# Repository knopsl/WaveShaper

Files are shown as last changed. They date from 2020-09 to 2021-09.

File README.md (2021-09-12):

# VC 4046 Wave Shaper

**Prototype has been tested, some issues found. Corrected version not yet tested! ASSUME NOTHING WORKS UNTIL THIS NOTICE IS REMOVED!**

This is a modification of the Barton Musical Circuits [4046 Wave Shaper](http://www.bartonmusicalcircuits.com/4046/), a module described by Barton as follows:

> This is an all analog synthesizer module used to create new timbres and waveforms with your existing VCOs. It uses a CD4046 phase locked loop chip in combination with a binary counter to multiply the frequency of the input signal. It then has 7 outputs divided down from that multiplied frequency which are mixed together. It's simple to use and has a distinct sound.

In Barton's design the seven signals (which are 0, 1, 2, and 3 octaves above and below the input signal) go into a simple mixer with a potentiometer attenuator on each channel to produce the module output. This modification replaces that simple mixer with a voltage controlled mixer, allowing use of control voltages to modulate the mix. If any of the seven control voltage jacks does not have anything plugged in, the CV is normalled to +10 V allowing the pot to behave like a signal attenuator.

An additional modification to Barton's design is that the gain on the output stage can be varied using a pot on the panel. This allows reducing the gain to avoid clipping when mixing multiple large signals, avoiding the need to turn down all the channel pots and allowing use of their full range.

The module consists of a front panel and three PCBs. One of these is the PCB for the original 4046 Wave Shaper, available from Barton, assembled mostly as designed but with a few things changed. The second is a PCB holding the board mounted pots and switch as well as the parts associated with the voltage controlled mixer and the power input section. The third just holds the board mounted input and output jacks.

## Photos

to be added

## Documentation

* [Schematic](Docs/waveshaper.pdf)
* PCB layout: [front](Docs/waveshaper_layout_front.pdf), [back](Docs/waveshaper_layout_back.pdf)
* [BOM](Docs/waveshaper_bom.md)
* [Build notes](Docs/build.md)

## GitHub repository

* [https://github.com/holmesrichards/WaveShaper](https://github.com/holmesrichards/WaveShaper)

## Submodules

This repo uses submodules aoKicad and Kosmo_panel, needed by KiCad. To clone:

```
git clone git@github.com:holmesrichards/WaveShaper.git
git submodule init
git submodule update
```

Alternatively do

```
git clone --recurse-submodules git@github.com:holmesrichards/WaveShaper.git
```

Or if you download the repository as a zip file, you must also click on the "aoKicad" and "Kosmo\_panel" links on the GitHub page (they'll have "@ something" after them) and download them as separate zip files which you can unzip into this repo's aoKicad and Kosmo\_panel directories.

If desired, copy the files from aoKicad and Kosmo\_panel to wherever you prefer (your KiCad user library directory, for instance, if you have one). Then in KiCad, add symbol libraries 

```
aoKicad/ao_symbols
Kosmo_panel/Kosmo
```
and footprint libraries 
```
aoKicad/ao_tht
Kosmo_panel/Kosmo_panel.
```

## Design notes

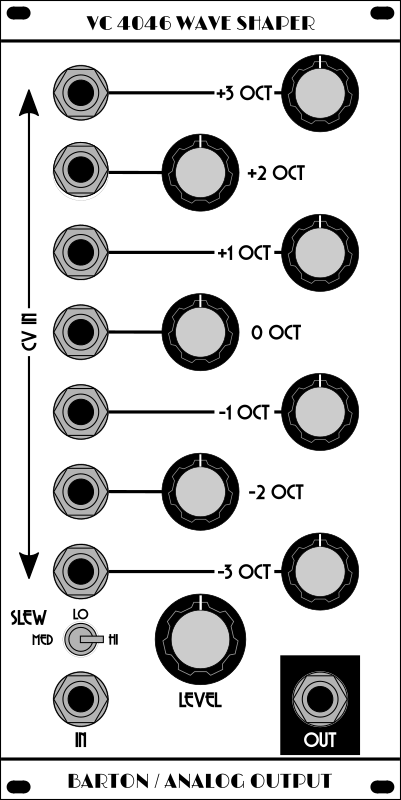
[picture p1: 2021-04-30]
Hardware/Panel/waveshaper.png

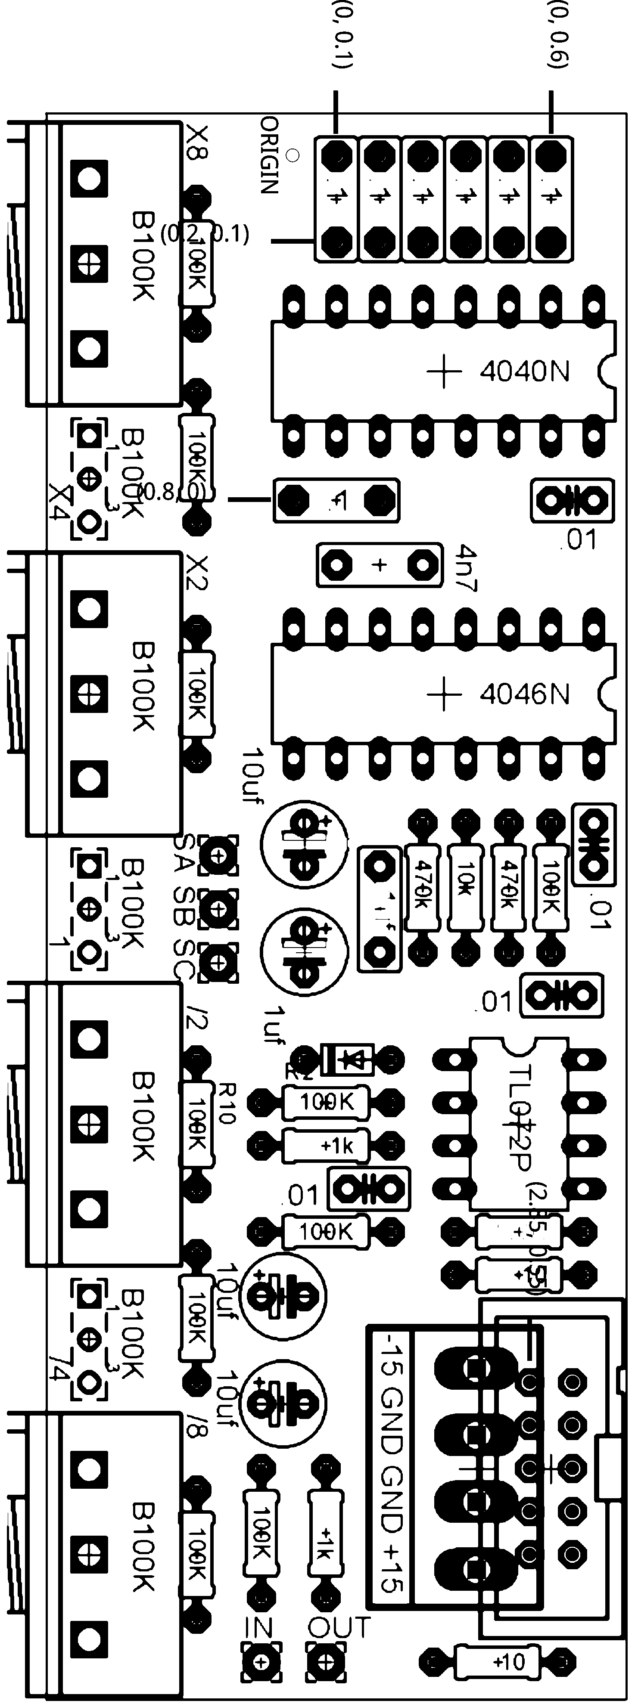
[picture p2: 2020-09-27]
Hardware/PCB-aux/waveshaper-aux/waveshaper_bartonboardbw.png

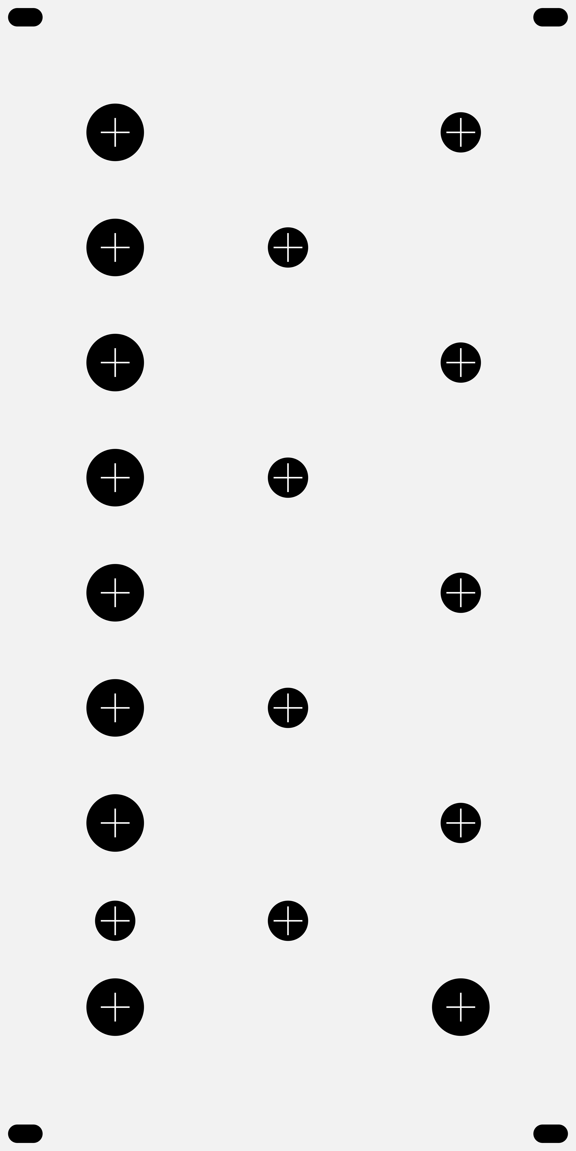
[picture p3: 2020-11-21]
Hardware/Panel/waveshaper_holes.png

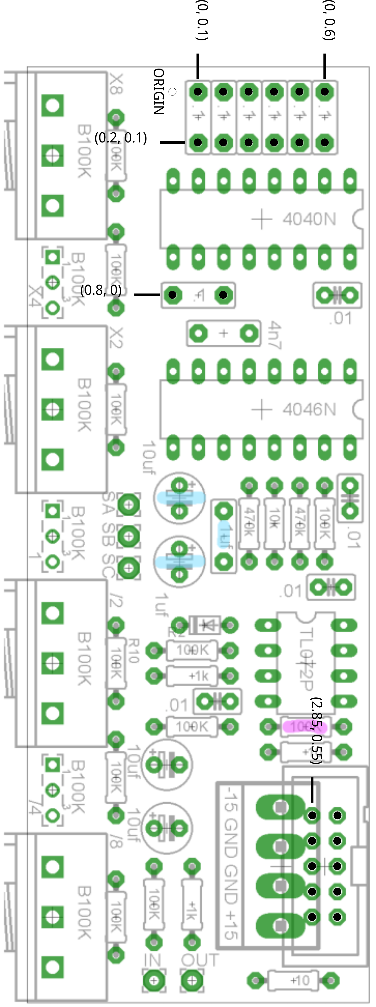
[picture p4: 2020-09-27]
Hardware/PCB-aux/waveshaper-aux/waveshaper_bartonboard.png

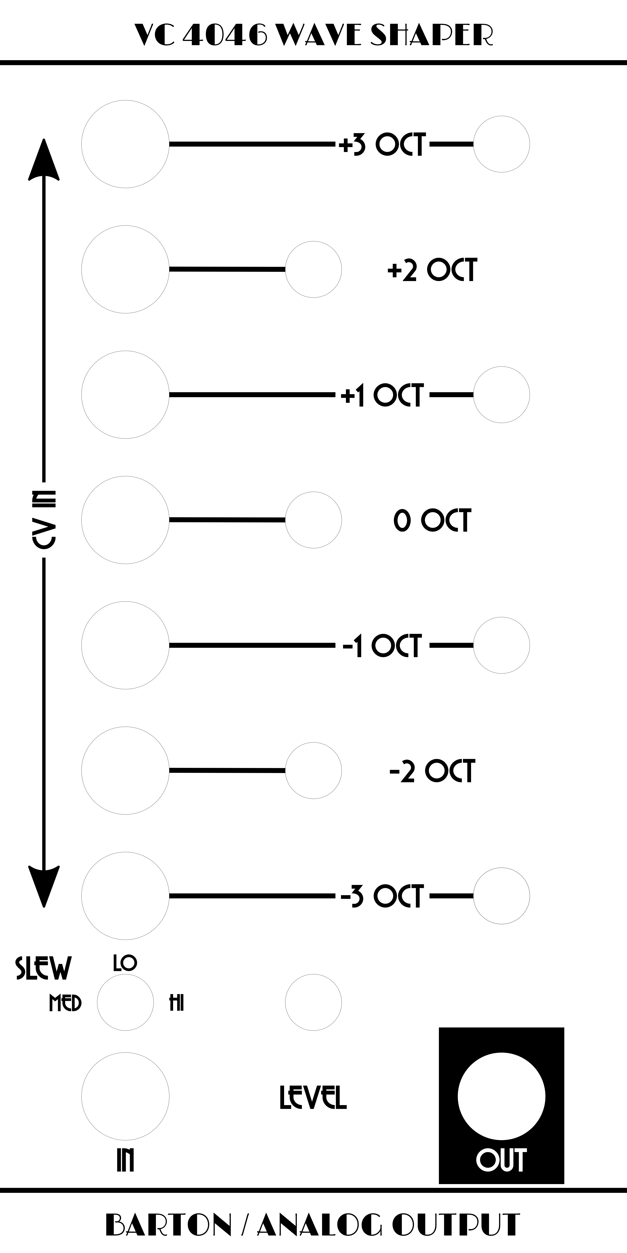
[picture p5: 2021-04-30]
Hardware/Panel/waveshaper_art.png

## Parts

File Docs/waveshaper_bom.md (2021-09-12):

# waveshaper.sch BOM

Sat 11 Sep 2021 09:26:15 PM EDT

Generated from schematic by Eeschema 5.1.10-88a1d61d58~90~ubuntu20.04.1

**Component Count:** 57

| Refs | Qty | Component | Description | Vendor | SKU |
| ----- | --- | ---- | --- | ---- | ---- |
| C1, C2 | 2 | 10uF | Polarized capacitor | Tayda | A-4349 |
| C3, C4 | 2 | 0.1uF | Unpolarized capacitor | Tayda | A-553 |
| D1, D2, D3, D4, D5, D6, D7, D8, D9 | 9 | 1N5817 | Schottky Barrier Rectifier Diode, DO-41 | Tayda | A-159 |
| J1 | 1 | 2x7 IDC header | Generic connector, double row, 02x07, odd/even pin numbering scheme (row 1 odd numbers, row 2 even numbers), script generated (kicad-library-utils/schlib/autogen/connector/) | Tayda | A-3349 |
| J2, J3, J6, J10, J12, J14, J15, J16, J17 | 9 | AudioJack2_SwitchT | Audio Jack, 2 Poles (Mono / TS), Switched T Pole (Normalling) | Tayda | A-1121 |
| J4, J8 | 2 | 2_pin_Molex_header | KK254 Molex header | Tayda | A-804 |
| J5 | 1 | EURO_PWR_2x5 | Pin header 2.54 mm 2x5 | Tayda | A-2939 |
| J7 | 1 | Conn_01x9 | Generic connector, single row, 01x09, script generated (kicad-library-utils/schlib/autogen/connector/) |  |  |
| J9 | 1 | Conn_01x9 | Generic connector, single row, 01x09, script generated (kicad-library-utils/schlib/autogen/connector/) |  |  |
| J11 | 1 | 3_pin_Molex_header | KK254 Molex header | Tayda | A-805 |
| J13 | 1 | 2x5 pin socket | Generic connector, double row, 02x05, odd/even pin numbering scheme (row 1 odd numbers, row 2 even numbers), script generated (kicad-library-utils/schlib/autogen/connector/) |  |  |
| R1, R2, R3, R4, R5, R6, R7 | 7 | 10k | Resistor |  |  |
| R8 | 1 | 100k | Resistor |  |  |
| R9 | 1 | 470k | Resistor |  |  |
| R10, R11, R12, R13, R14, R15, R16 | 7 | 1k |  | Tayda |  |
| RV1, RV3, RV4, RV5, RV6, RV7, RV8 | 7 | B100k | Potentiometer | Tayda | A-1848 |
| RV2 | 1 | A100k | Potentiometer | Tayda | A-1855 |
| SW1 | 1 | SW_SPDT | Switch, single pole double throw | Tayda | A-3187 |
| U1, U2 | 2 | 4066 | Quad Analog Switches | Tayda | A-555 |

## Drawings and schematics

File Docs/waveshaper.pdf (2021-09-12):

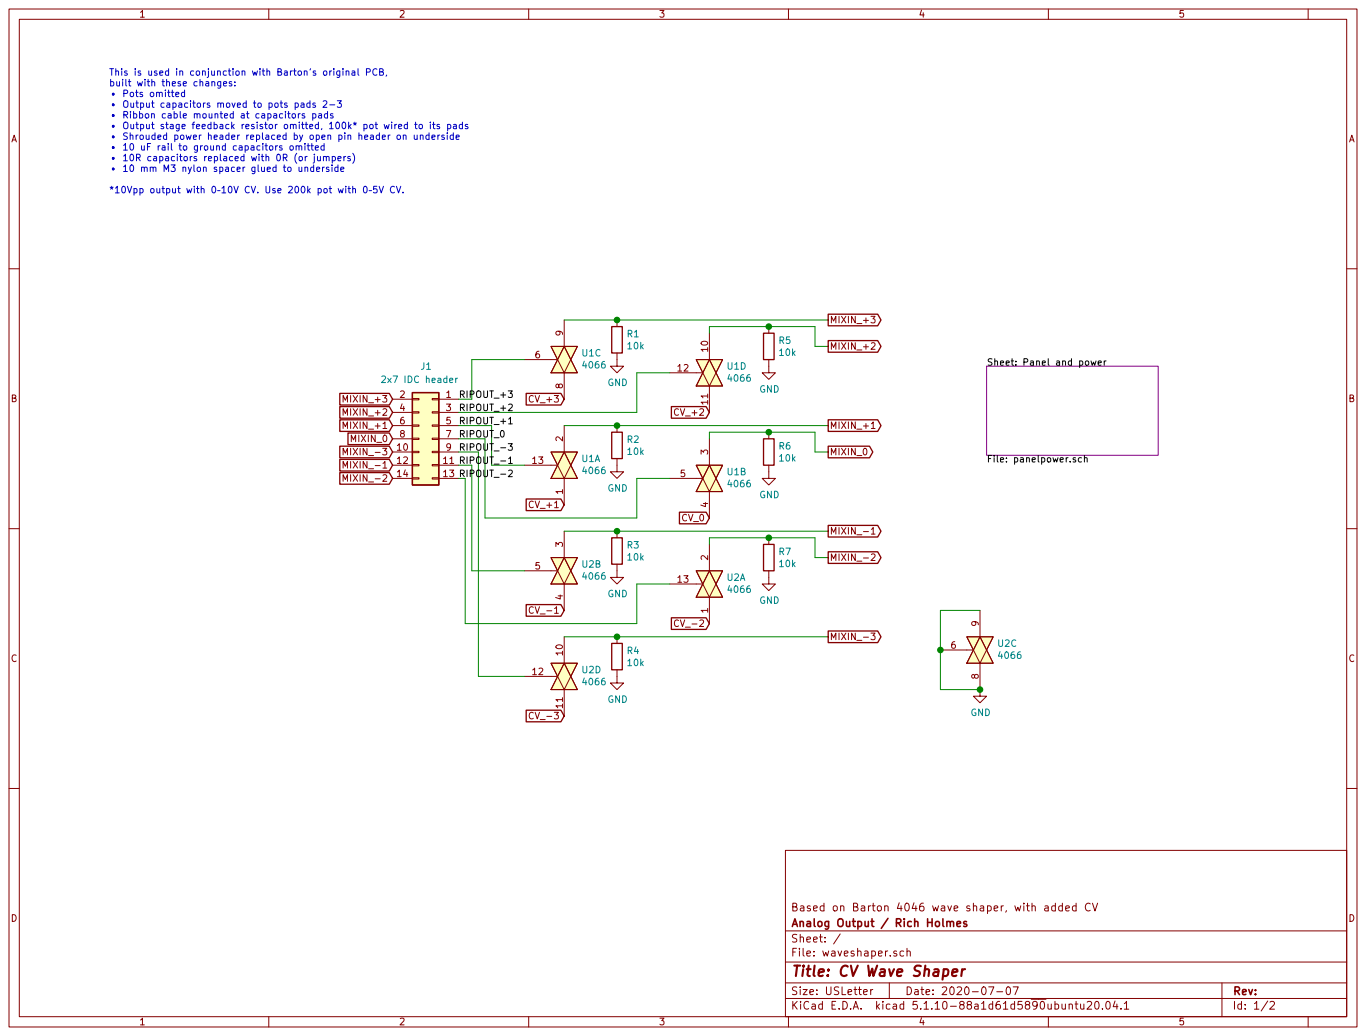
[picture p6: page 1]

built with these changes:
Pots omitted
Output capacitors moved to pots pads 2-3
Ribbon cable mounted at capacitors pads
Output stage feedback resistor omitted, 100k* pot wired to its pads
Shrouded power header replaced by open pin header on underside
10 uF rail to ground capacitors omitted
10R capacitors replaced with 0R (or jumpers)
10 mm M3 nylon spacer glued to underside

*10Vpp output with 010V CV. Use 200k pot with 05V CV.

Sheet: Panel and power

File: panelpower.sch GND

Based on Barton 4046 wave shaper, with added CV
File: waveshaper.sch Sheet: / Analog Output / Rich Holmes

Id: 1/2 Title: CV Wave Shaper

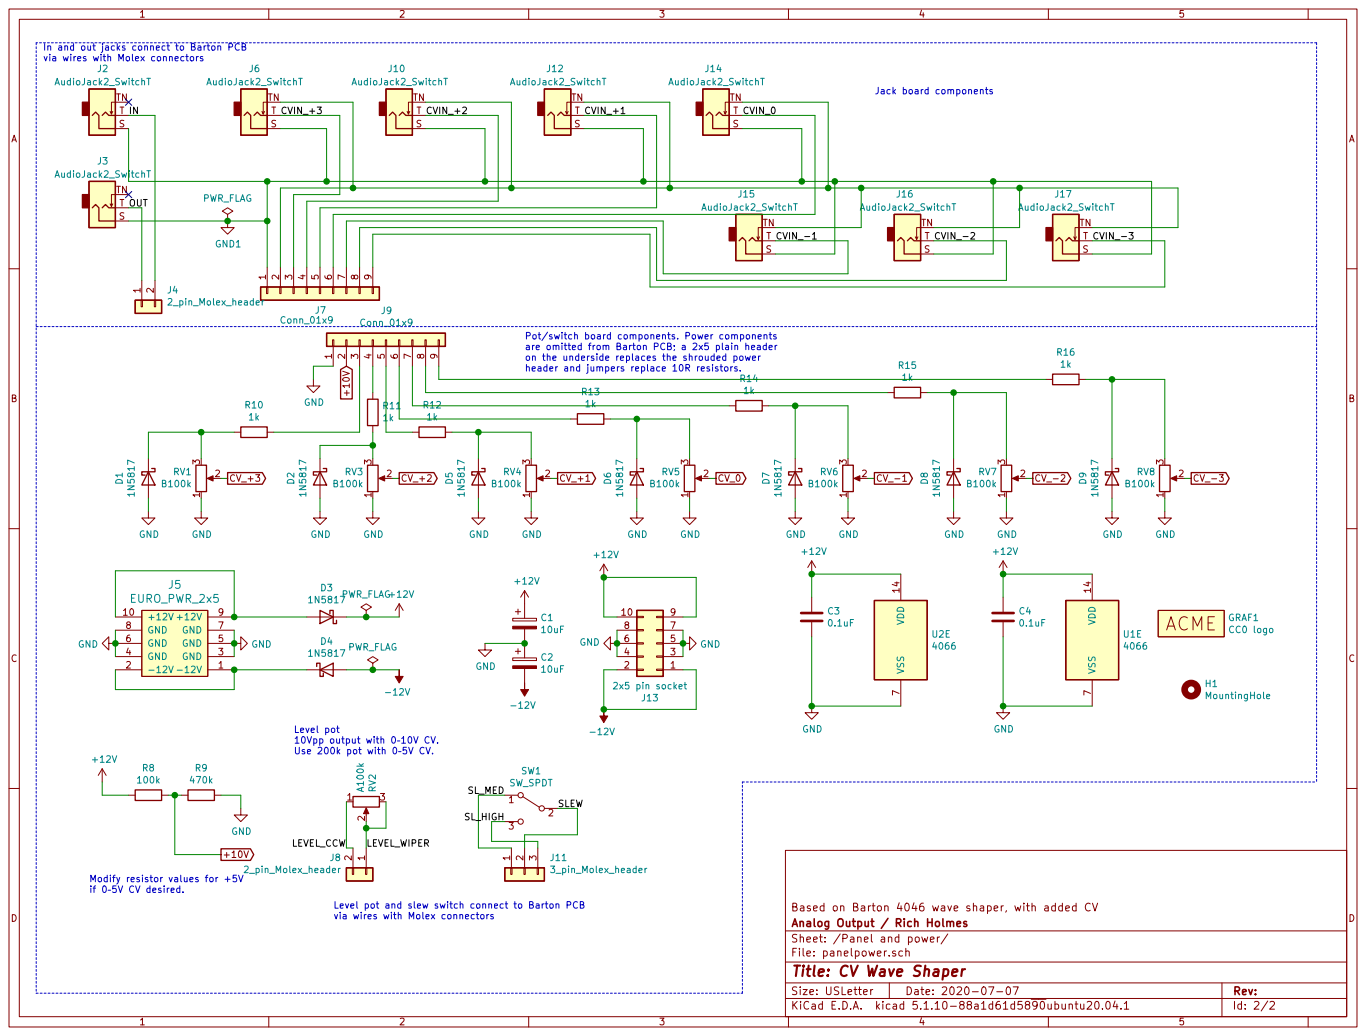
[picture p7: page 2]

In and out jacks connect to Barton PCB via wires with Molex connectors

Pot/switch board components. Power components
are omitted from Barton PCB; a 2x5 plain header
on the underside replaces the shrouded power
header and jumpers replace 10R resistors.

Level pot
10Vpp output with 010V CV.
Use 200k pot with 05V CV.

Level pot and slew switch connect to Barton PCB via wires with Molex connectors Modify resistor values for +5V
if 05V CV desired.

Based on Barton 4046 wave shaper, with added CV
Analog Output / Rich Holmes
Sheet: /Panel and power/
File: panelpower.sch
Id: 2/2 Title: CV Wave Shaper

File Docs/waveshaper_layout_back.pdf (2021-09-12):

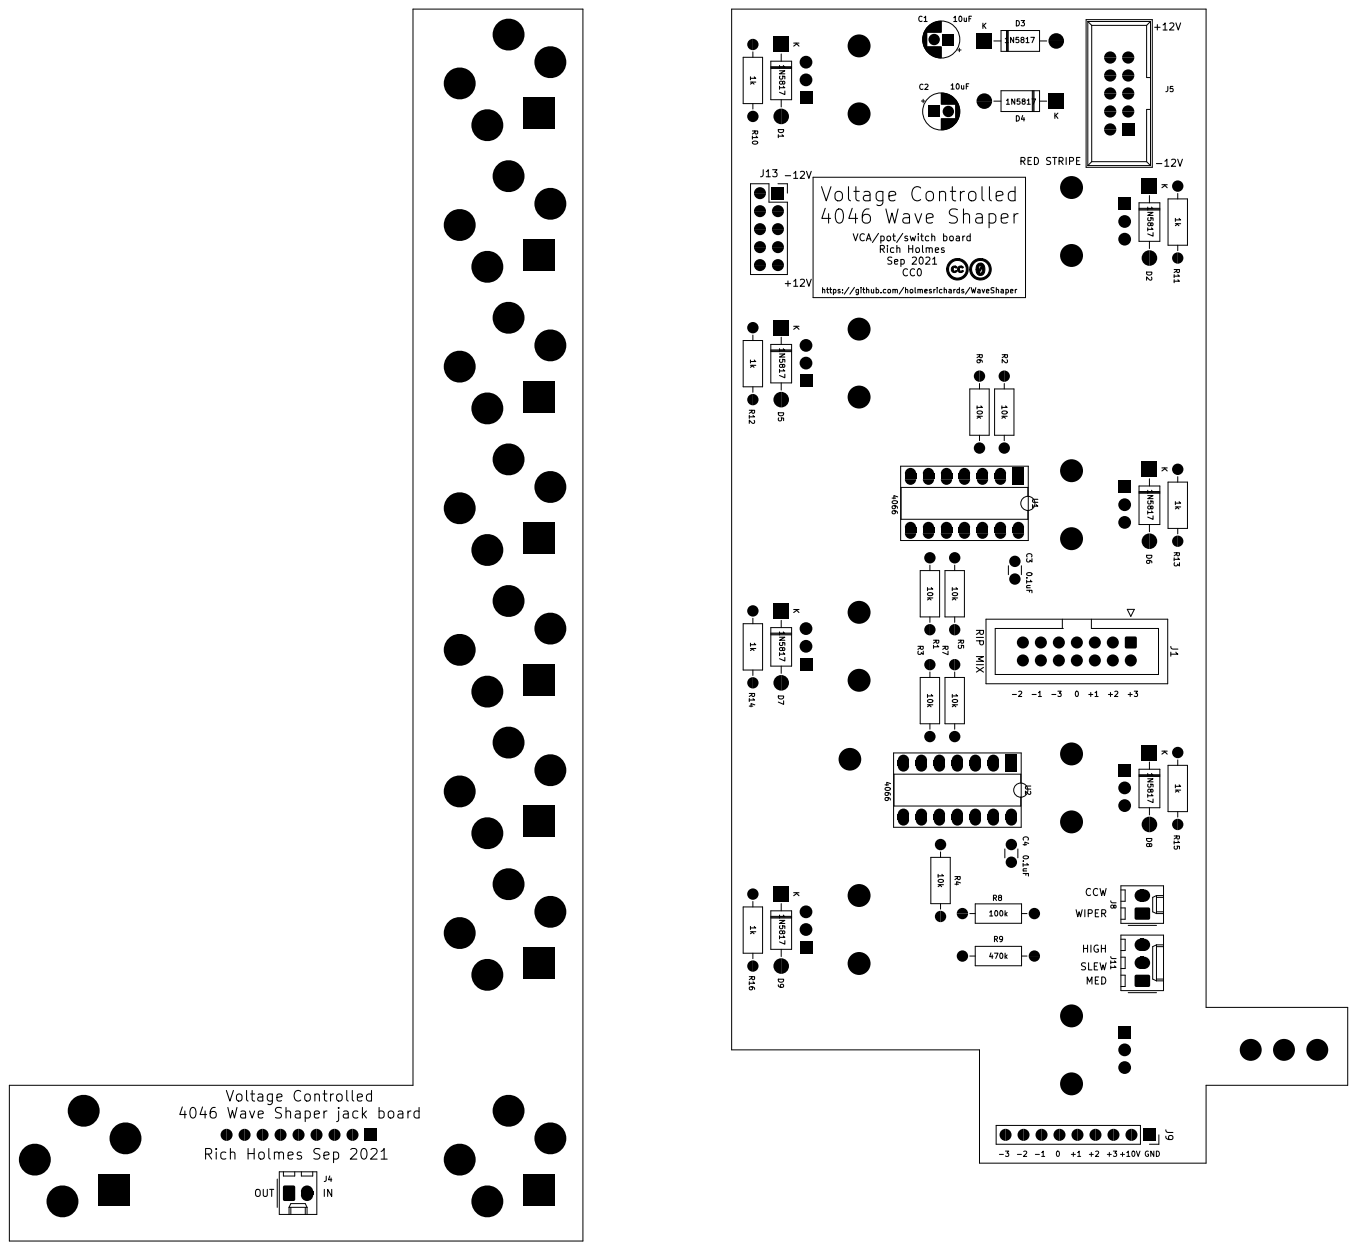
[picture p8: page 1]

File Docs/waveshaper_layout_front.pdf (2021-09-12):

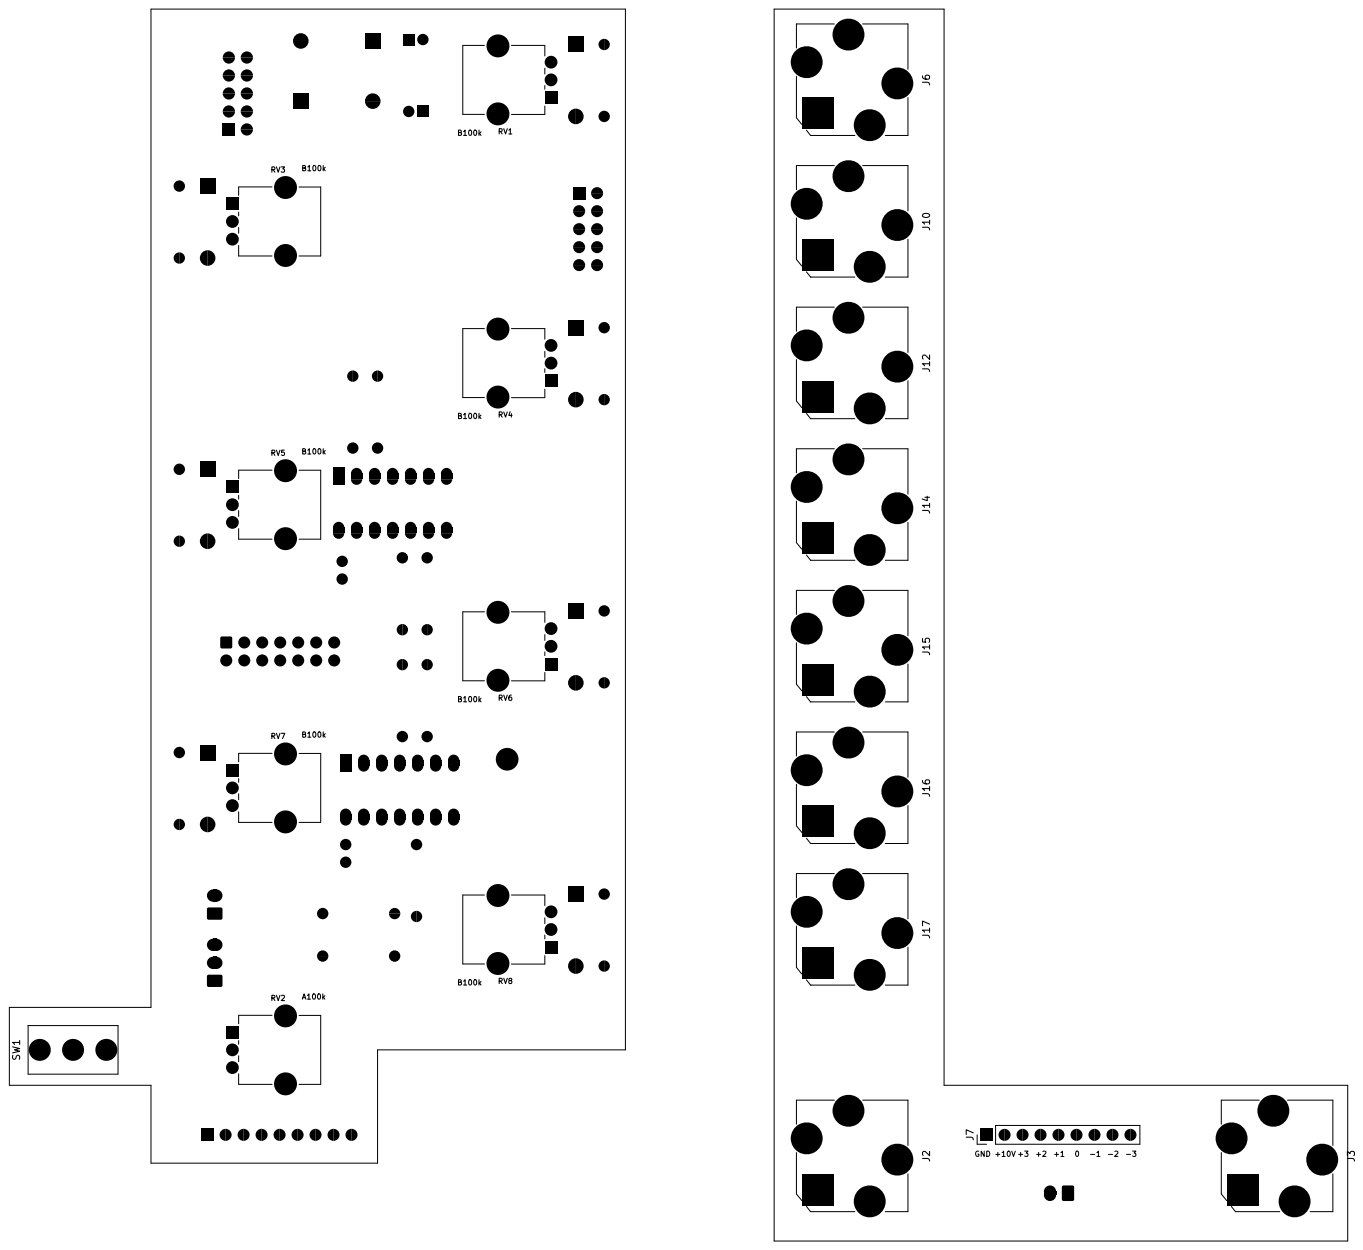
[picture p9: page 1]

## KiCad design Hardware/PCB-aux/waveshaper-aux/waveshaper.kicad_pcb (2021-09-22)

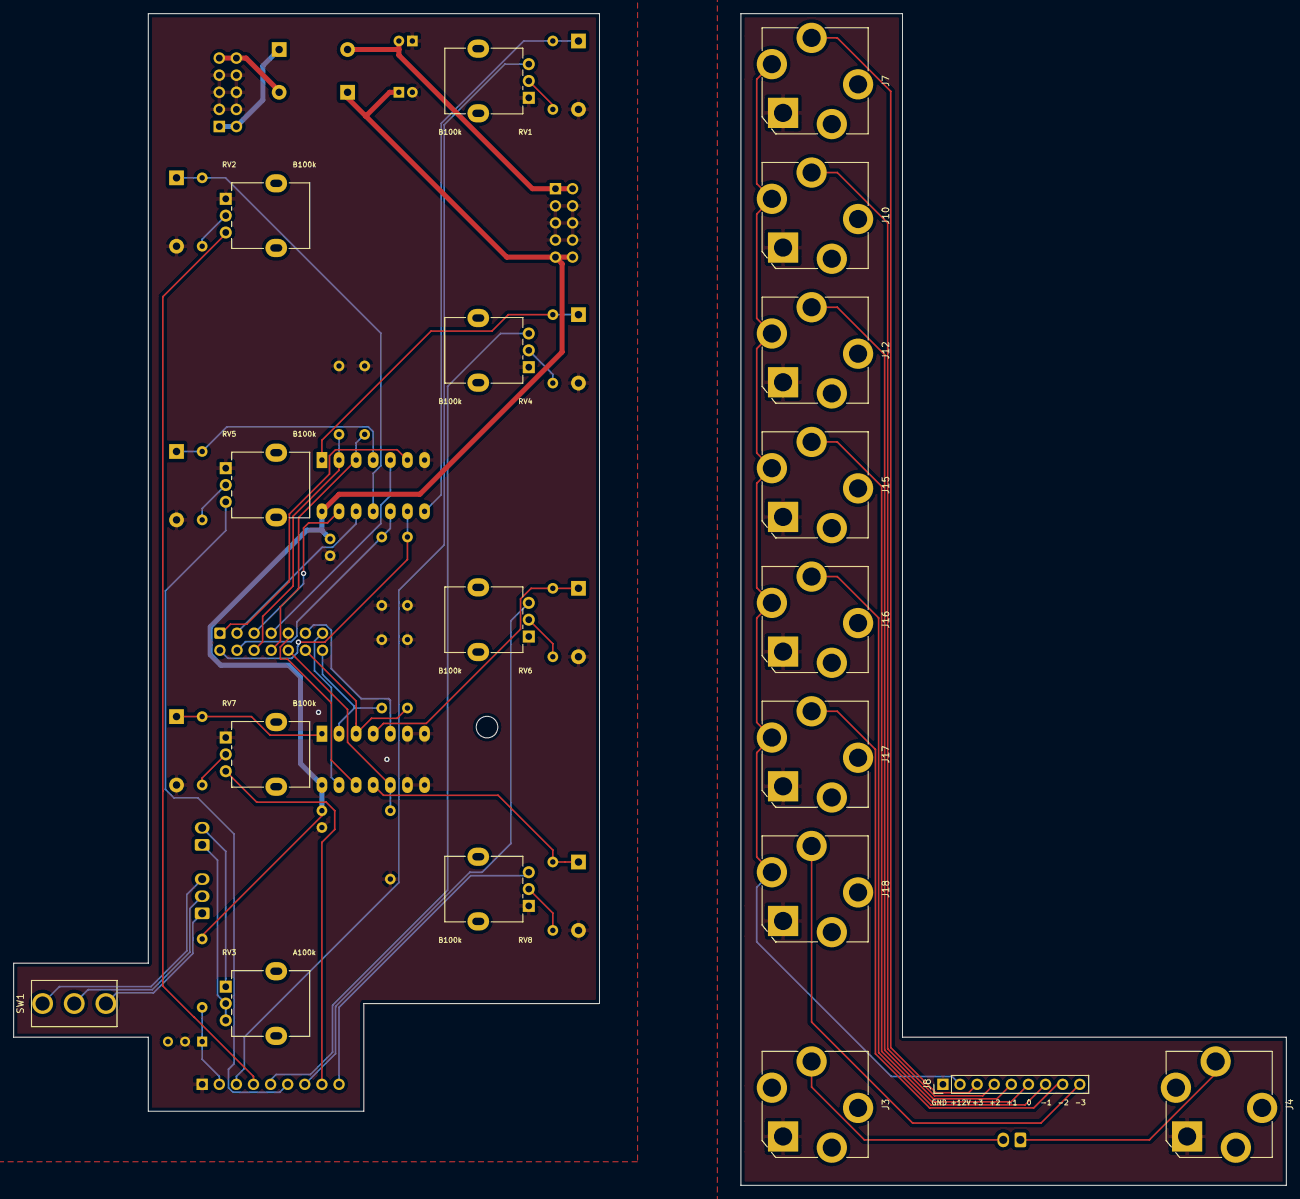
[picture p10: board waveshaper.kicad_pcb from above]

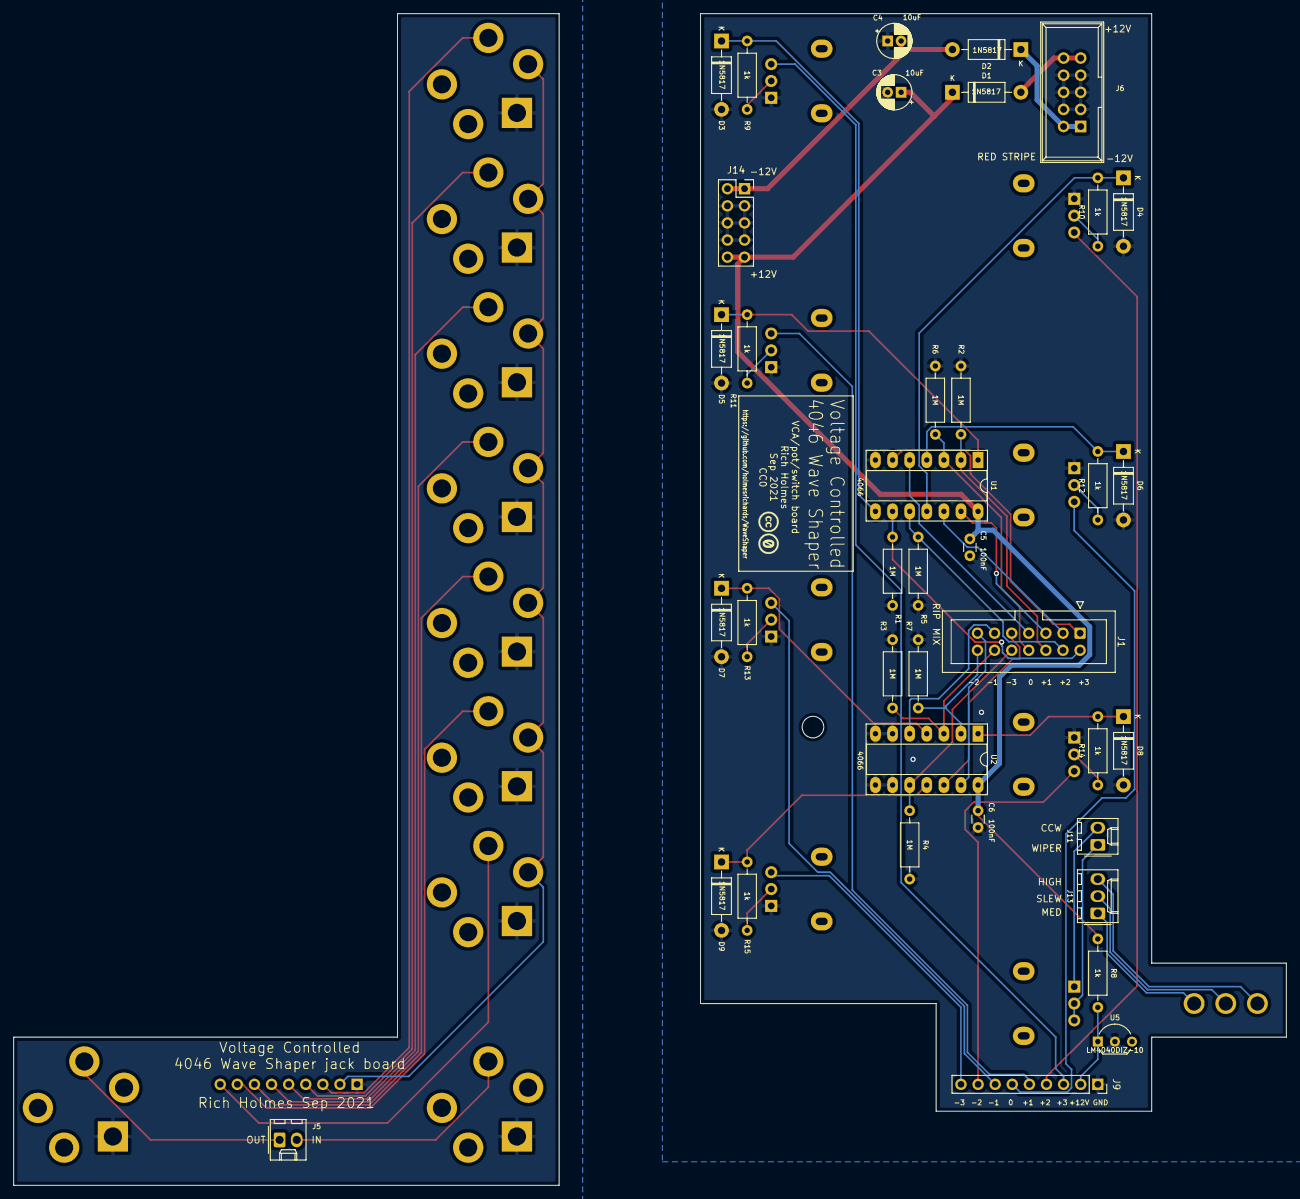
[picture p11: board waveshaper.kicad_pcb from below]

Board: 2 copper layers, 87.0 x 163.0 mm, 60 parts (39 on the bottom side), 57 nets.

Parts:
C3, C4: 10uF; CP_Radial_D5.0mm_P2.00mm
C5, C6: 100nF; C_Disc_D3.0mm_W1.6mm_P2.50mm
D1, D2, D3, D4, D5, D6, D7, D8, D9: 1N5817; D_DO-41_SOD81_P10.16mm_Horizontal
GRAF1: CC0 logo; CC0_logo
GRAF2: Holes; waveshaper-holes
H1: MountingHole; MountingHole_3.2mm_M3
J1: 2x7 IDC header; IDC-Header_2x07_P2.54mm_Vertical
J3, J4, J7, J10, J12, J15, J16, J17, J18: AudioJack2_SwitchT; Jack_6.35mm_PJ_629HAN
J5, J11: 2_pin_Molex_header; Molex_KK-254_AE-6410-02A_1x02_P2.54mm_Vertical
J6: EURO_PWR_2x5; Power_Header
J8: Conn_01x9; PinHeader_1x09_P2.54mm_Vertical
J9: Conn_01x9; PinSocket_1x09_P2.54mm_Vertical
J13: 3_pin_Molex_header; Molex_KK-254_AE-6410-03A_1x03_P2.54mm_Vertical
J14: 2x5 pin socket; PinSocket_2x05_P2.54mm_Vertical
R1, R2, R3, R4, R5, R6, R7: 1M; R_Axial_DIN0207_L6.3mm_D2.5mm_P10.16mm_Horizontal
R8, R9, R10, R11, R12, R13, R14, R15: 1k; R_Axial_DIN0207_L6.3mm_D2.5mm_P10.16mm_Horizontal
RV1, RV2, RV4, RV5, RV6, RV7, RV8: B100k; Potentiometer_Alpha_RD901F-40-00D_Single_Vertical
RV3: A100k; Potentiometer_Alpha_RD901F-40-00D_Single_Vertical
SW1: SW_SPDT; SPDT-toggle-switch-1M-series
U1, U2: 4066; DIP-14_W7.62mm_Socket_LongPads
U5: LM4040DIZ-10; TO-92_Inline_Wide

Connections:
+10V: J9.2, R8.2, U5.1
+12V: C3.1, C5.1, C6.1, D1.1, J14.9, J14.10, R8.1, U1.14, U2.14
-12V: C4.2, D2.2, J14.1, J14.2
/Panel and power/+12V_IN: D1.2, J6.9, J6.10
/Panel and power/-12V_IN: D2.1, J6.1, J6.2
/Panel and power/CVIN_0: J8.6, J15.T
/Panel and power/CVIN_+1: J8.5, J12.T
/Panel and power/CVIN_+2: J8.4, J10.T
/Panel and power/CVIN_+3: J7.T, J8.3
/Panel and power/CVIN_-1: J8.7, J16.T
/Panel and power/CVIN_-2: J8.8, J17.T
/Panel and power/CVIN_-3: J8.9, J18.T
/Panel and power/IN: J3.T, J5.2
/Panel and power/LEVEL_CCW: J11.2, RV3.1
/Panel and power/LEVEL_WIPER: J11.1, RV3.2, RV3.3
/Panel and power/OUT: J4.T, J5.1
/Panel and power/SLEW: J13.2, SW1.2
/Panel and power/SL_HIGH: J13.3, SW1.3
/Panel and power/SL_MED: J13.1, SW1.1
/RIPOUT_0: J1.7, U1.5
/RIPOUT_+1: J1.5, U1.13
/RIPOUT_+2: J1.3, U1.12
/RIPOUT_+3: J1.1, U1.6
/RIPOUT_-1: J1.11, U2.5
/RIPOUT_-2: J1.13, U2.13
/RIPOUT_-3: J1.9, U2.12
CV_0: D6.1, R12.2, U1.4
CV_+1: D5.1, R11.2, U1.1
CV_+2: D4.1, R10.2, U1.11
CV_+3: D3.1, R9.2, U1.8
CV_-1: D7.1, R13.2, U2.4
CV_-2: D8.1, R14.2, U2.1
CV_-3: D9.1, R15.2, U2.11
GND: C3.2, C4.1, C5.2, C6.2, D3.2, D4.2, D5.2, D6.2, D7.2, D8.2, D9.2, J6.3, J6.4, J6.5, J6.6, J6.7, J6.8, J9.1, J14.3, J14.4, J14.5, J14.6, J14.7, J14.8, R1.2, R2.2, R3.2, R4.2, R5.2, R6.2, R7.2, RV1.1, RV2.1, RV4.1, RV5.1, RV6.1, RV7.1, RV8.1, U1.7, U2.6, U2.7, U2.8, U2.9, U5.2
GND1: J3.S, J4.S, J7.S, J8.1, J10.S, J12.S, J15.S, J16.S, J17.S, J18.S
MIXIN_0: J1.8, R6.1, U1.3
MIXIN_+1: J1.6, R2.1, U1.2
MIXIN_+2: J1.4, R5.1, U1.10
MIXIN_+3: J1.2, R1.1, U1.9
MIXIN_-1: J1.12, R3.1, U2.3
MIXIN_-2: J1.14, R7.1, U2.2
MIXIN_-3: J1.10, R4.1, U2.10
unnamed: J9.3, RV1.3
unnamed: J9.4, RV2.3
unnamed: J9.5, RV4.3
unnamed: J9.6, RV5.3
unnamed: J9.7, RV6.3
unnamed: J9.8, RV7.3
unnamed: J9.9, RV8.3
unnamed: J7.TN, J8.2, J10.TN, J12.TN, J15.TN, J16.TN, J17.TN, J18.TN
unnamed: R9.1, RV1.2
unnamed: R10.1, RV2.2
unnamed: R11.1, RV4.2
unnamed: R12.1, RV5.2
unnamed: R13.1, RV6.2
unnamed: R14.1, RV7.2
unnamed: R15.1, RV8.2

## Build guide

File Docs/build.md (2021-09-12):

# VC 4046 Wave Shaper build notes

## PCB assembly
To build this module you need to assemble three PCBs. One holds the board mounted jacks and connects via a pin header/socket pair to the second which holds board mounted pots and switch as well as components relating to the voltage controlled mixer and power input. Both are very straightforward to build. There are three Molex headers for wires leading to the main board; if you prefer of course you can skip the Molex and just solder these wires.

Pay attention to the silkscreen which indicates which side to fit the components on. The jacks, switch, pots, and jack board pin header face the front of the module. All other components on these two boards face the back.

The main PCB is the original Barton circuit board for the 4046 Wave Shaper. It is available from [Barton Musical Circuits](http://www.bartonmusicalcircuits.com), [Modular Addict](https://modularaddict.com), or [SynthCube](https://synthcube.com). This board is to be assembled as designed, except for the following modifications:

* Omit the pots.
* Move the 7 100 nF (0.1 µF) output capacitors (6 footprints to one side of the 4040N and 1 footprint to the other side) to pads 2 and 3 of the pot footprints.
* Solder a 14 conductor ribbon cable to the vacant capacitor footprints (see below).
* Omit the 100k output stage feedback resistor located at the end of the TL072. Instead solder here two wires to be connected to the pot/switch board. A pair of wires peeled off a rainbow ribbon cable works well. In addition, as designed, solder two wires to the IN/OUT pins, and three wires to the SA/SB/SC pins.
* Instead of a 10 pin header on the component side, fit an unshrouded 10 pin header (2x5) **on the reverse side.**
* Omit the two 10 µF rail to ground capacitors.
* Replace the two 10R resistors with jumpers or 0R resistors.

## Final assembly

First secure a 10 mm Nylon spacer to the pot/switch board using the mounting hole.

The board mounted pots, switch, and jacks are used to secure two of the PCBs to the front panel, with the pin header on one plugging in to the pin socket on the other. 

Plug the main PCB's 10 pin header into the 10 pin socket on the pot/switch board. **Check to make sure the header and socket are aligned correctly.** 

Fit a 14 pin IDC connector to the ribbon cable, making sure to get the orientation correct (see below). The cable should be cut to reach the 14 pin shrouded header on the pot/switch board. Plug it in.

Fit two 2 pin Molex connectors to the IN/OUT wires and the wires soldered to the 100k resistor footprint, and a 3 pin Molex connector to the wires connected to SA/SB/SC. The wires should be cut to reach the Molex headers on the other two boards; see silkscreen to determine which wire goes where in the Molex connectors. (SA and SC go to High and Low, respectively. The 100k resistor wires can go either way.) Plug them in.

Now you can test the module to see if anything needs troubleshooting. Once you're happy, unplug the main board from the pot/switch board. Put a dab of epoxy on the end of the Nylon spacer. Replace the main board **(check the alignment again!)** and let the epoxy harden. 

Now see if you have 8 knobs that will fit.

## Ribbon cable

The conductors are numbered consecutively 1 to 14; the one with the red stripe is number 1. They are soldered as shown:

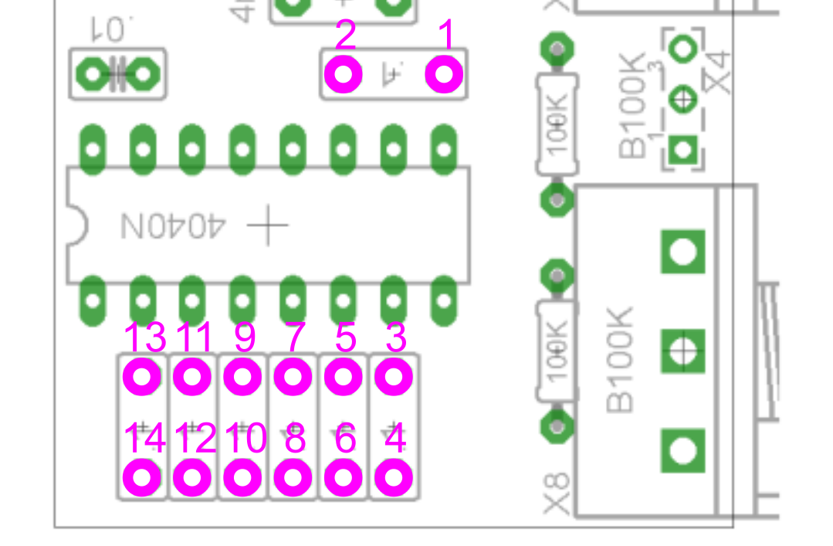
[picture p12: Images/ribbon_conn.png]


On the IDC connector, as with a Eurorack/Kosmo style power cable, pin 1 is on the top right when the orientation key is up. So the red stripe should be on the right.

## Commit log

2020-09-27 rm unused .sch
    [Synth_power.sch, panelpower.sch]
2020-10-03 Overdue commit: Boards redesign, docs folder
    [panelpower.sch, waveshaper.kicad_pcb, waveshaper.sch]
2020-10-09 Various tweaks
    [panelpower.sch, waveshaper.kicad_pcb, waveshaper.sch]
2020-10-25 14 pin connector -> IDC
    [waveshaper.kicad_pcb, waveshaper.sch]
2020-11-21 Directory reorg, panel work
    [panelpower.sch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]
2021-01-02 Footprints updated
2021-01-17 Include lib table files; new Gerbers
    [panelpower.sch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]
2021-02-19 Footprint update
2021-04-30 PCB tweak, font correction on panel
    [waveshaper-panel.kicad_pcb, waveshaper.kicad_pcb]
2021-08-07 Final tweaks before fabbing; Kosmo_panel lib update
    [panelpower.sch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]
2021-08-20 No NPTH specialization
    [waveshaper_panel_al-B_SilkS.gbr, waveshaper_panel_al-Edge_Cuts.gbr, waveshaper_panel_al-F_Cu.gbr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]
2021-08-29 Documentation, some cosmetic sch/PCB changes
    [panelpower.sch, waveshaper.kicad_pcb, waveshaper.sch]
2021-09-10 Mounting hole; parallel Schottkys instead of series switchers
    [panelpower.sch, waveshaper.kicad_pcb]
2021-09-11 Fix power polarity
    [waveshaper.kicad_pcb]
2021-09-12 Docs and minor corrections
    [waveshaper.kicad_pcb, waveshaper.sch]
2021-09-12 rm bad Gerbers
    [waveshaper-B_Cu.gbr, waveshaper-B_Mask.gbr, waveshaper-B_Paste.gbr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]
2021-09-12 Big redo: Add voltage ref, buffers; rm diodes
    [panelpower.sch, waveshaper.kicad_pcb, waveshaper.sch]
2021-09-13 Yes we need Schottkys
    [panelpower.sch, waveshaper.kicad_pcb]
2021-09-13 Make pulldowns 100k
    [waveshaper.kicad_pcb, waveshaper.sch]
2021-09-13 Use TL074
    [panelpower.sch, waveshaper.sch, waveshaperxy.kicad_pcb]
2021-09-13 Revert "Use TL074"
    This reverts commit 1a999078385277cd582d072a8d94e8801a268032.
    [panelpower.sch, waveshaper.kicad_pcb, waveshaper.sch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]
2021-09-15 rm op amp, reroute
    [panelpower.sch, waveshaper.kicad_pcb, waveshaper.sch]
2021-09-19 Trace tweaks, Gerbers
    [waveshaper-B_Cu.gbr, waveshaper-B_Mask.gbr, waveshaper-B_Paste.gbr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]
2021-09-22 Change pot footprint, new Gerbers
    [panelpower.sch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]
2021-09-22 Tiny adjustment
    [waveshaper-B_Cu.gbr, waveshaper-B_Mask.gbr, waveshaper-B_Paste.gbr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]
